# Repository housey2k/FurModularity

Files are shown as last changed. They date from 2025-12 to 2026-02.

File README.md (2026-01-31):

# FurModularity
Smart watch/audio mixer/module hub/game console/whatever
The FurModularity is a """watch""" meant "For Modularity", it's based on a ESP32-S3 as it's brain

It has 5 input/output connectors for external modules, these modules can be anything, be it a flashlight, a laser pointer, SD card, a second screen, or anything you can imagine, these modules interface with the main board through a SPI bus, a microcontroller inside the module card must interface between the actual module device and the ESP32, this allows more flexibility since a driver on the watch and custom code on the slave microcontroller allows for way more customization than directly interfacing the SPI bus with the module device, it would result in a way more limited module selection, or require you to manually select what kind of module is connected on the user inteface, which would ruin the hotplugging since you'd need to open settings every time you connect something new.

It also has a two input and two output audio mixer, via software you can route inputs 1, 2 or both to outputs 1, 2 or both, the routing is done by two 74VHC4066M Analog Switch ICs, one for each input channel, and you can also change the input volumes, that is done by two MCP4261 ICs, one for each channel too.

I originally built this project as a curious kid exploring CAD software, and I always liked electronics, I wanted to create my own stuff, but I never had the money for it. Now with more experience I restarted this project from scratch hoping to get funds for it.

This is how the PCB looks like, the back side has no components, thus simplifying assembly:

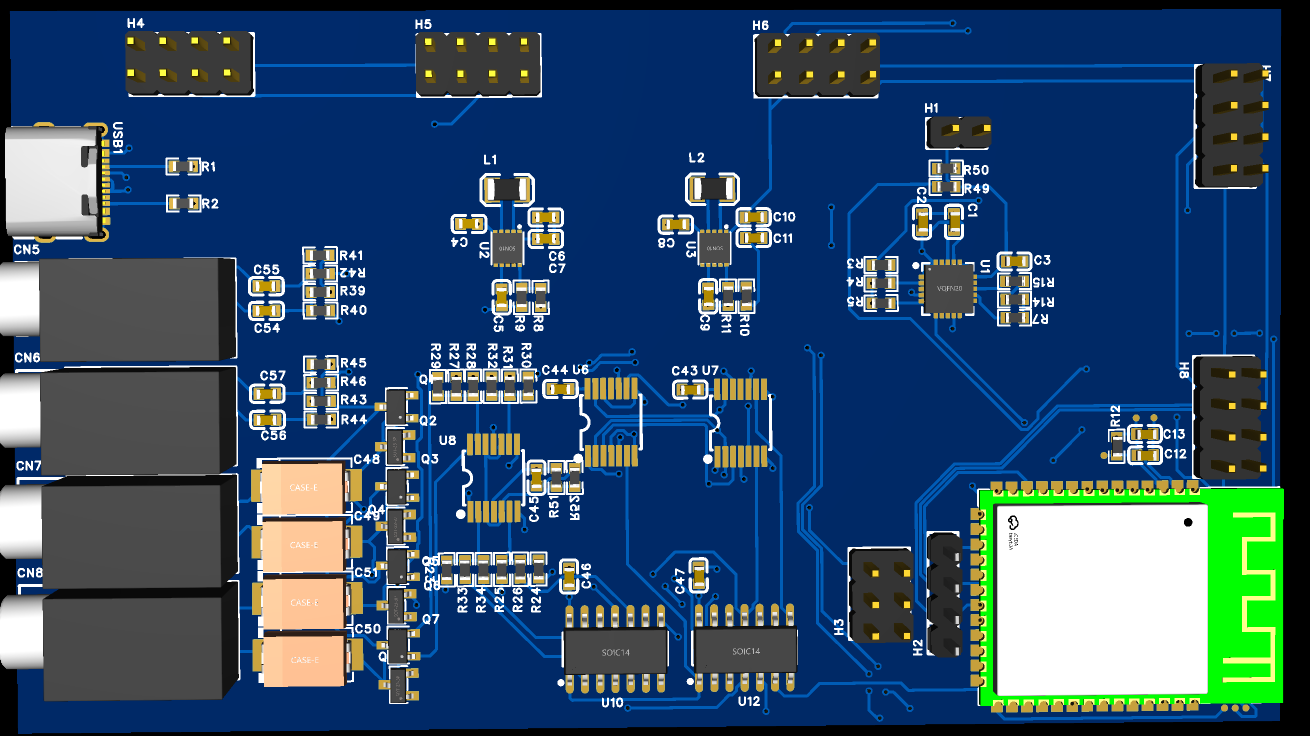
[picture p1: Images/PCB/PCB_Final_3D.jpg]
Board image

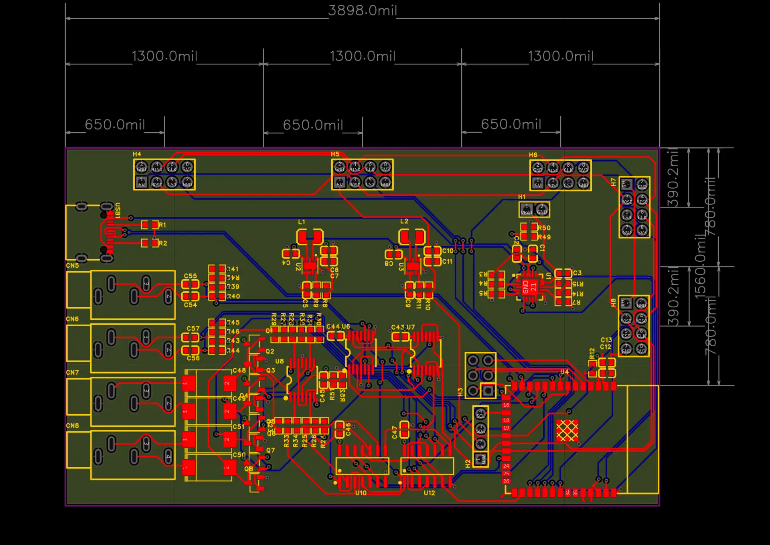
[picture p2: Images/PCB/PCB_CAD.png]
Board routing


This is how the case looks like:

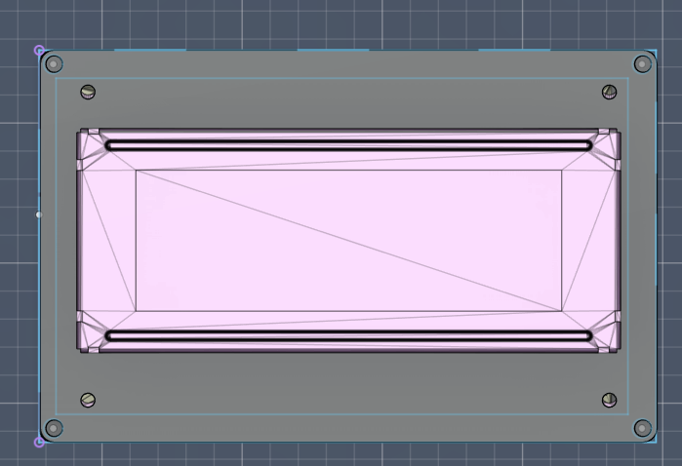
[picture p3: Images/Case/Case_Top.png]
Case

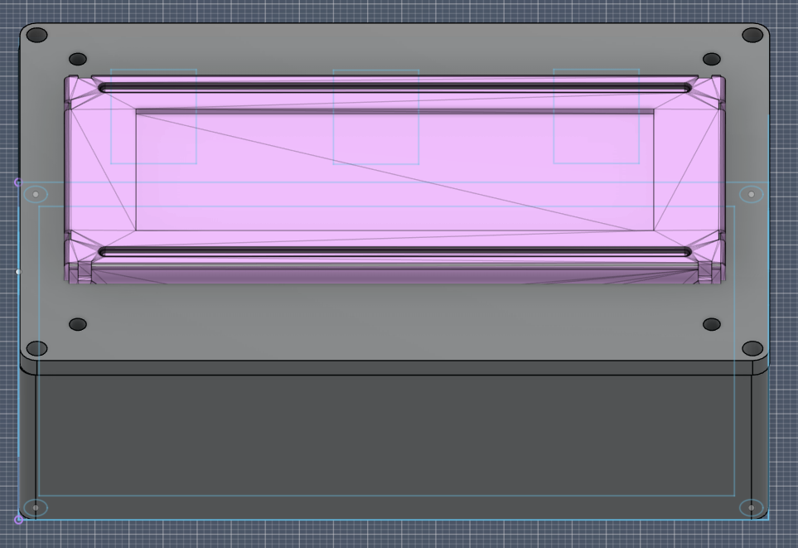
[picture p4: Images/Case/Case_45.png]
Case2

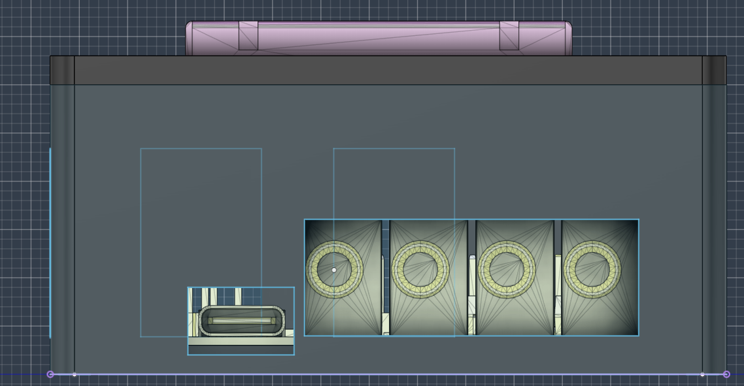
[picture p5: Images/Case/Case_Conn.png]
Case3

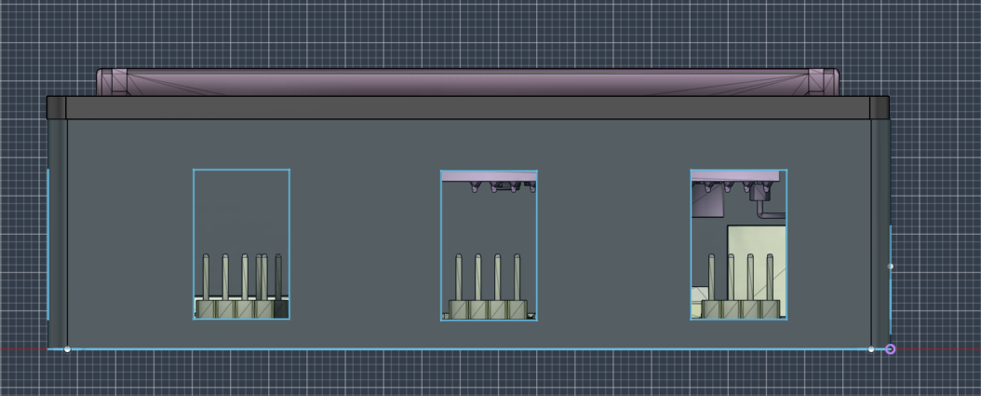
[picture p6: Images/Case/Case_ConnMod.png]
Case4


And finally, here is the schematics:
This is the power circuit, it handles battery discharging, PowerPath, and generating 5V and 3.3V rails

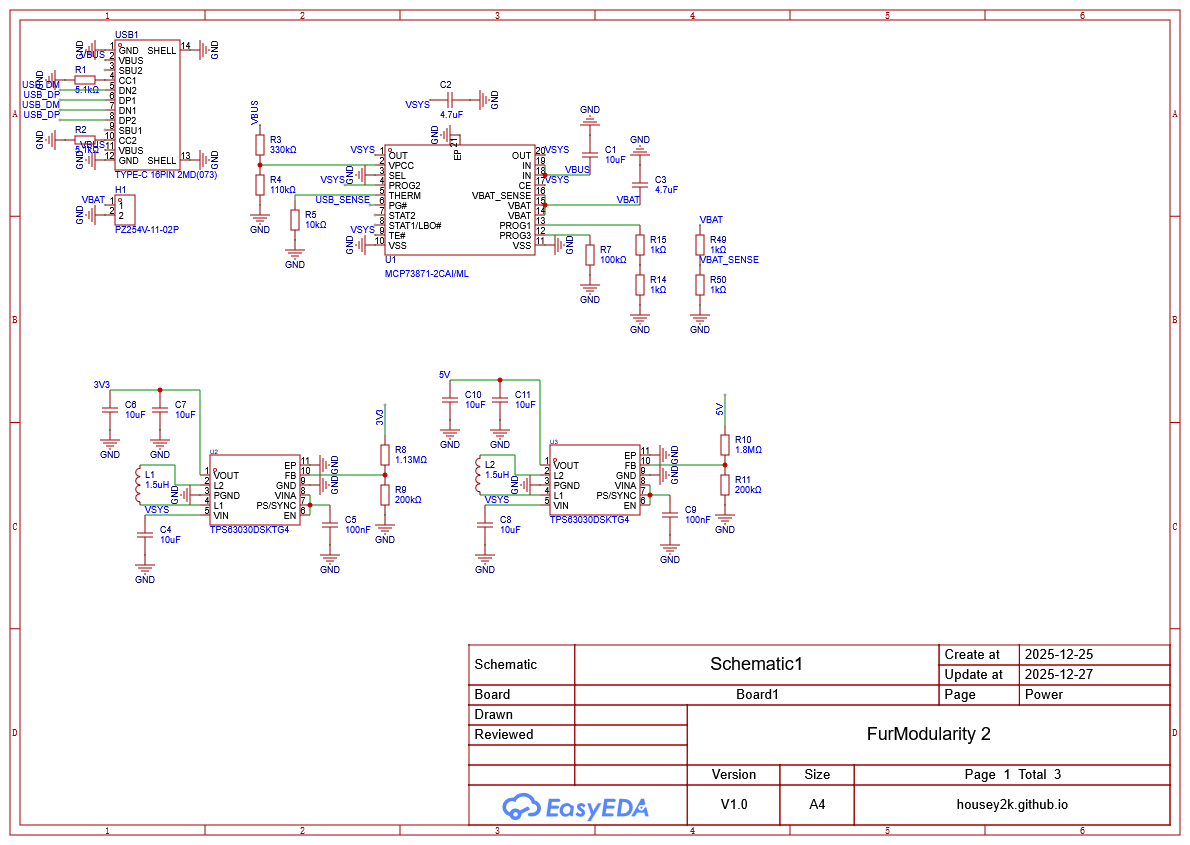
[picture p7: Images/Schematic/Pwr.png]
Power circuit


This is the digital circuit, it shows connections from the MCU to other components in the board

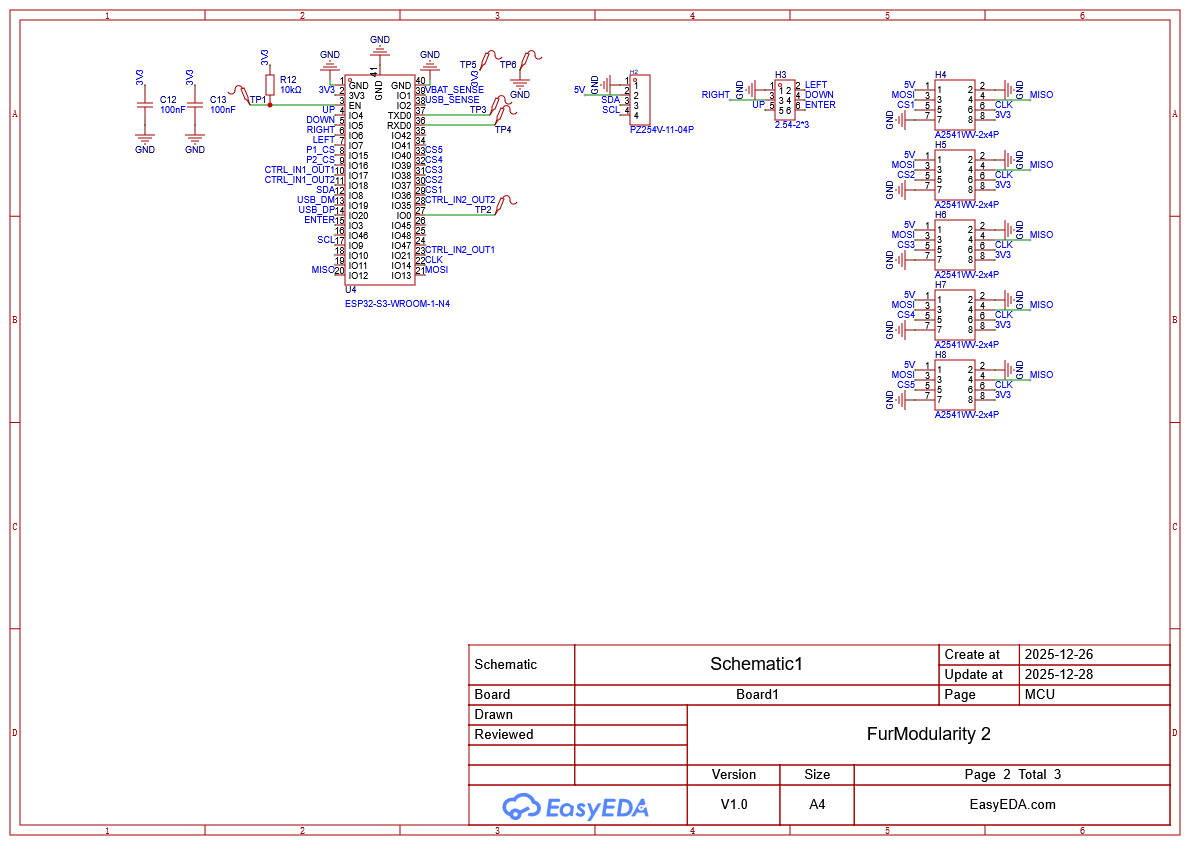
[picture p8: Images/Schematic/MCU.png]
Digital circuit


This is the audio circuit, it handles audio routing and volume control, everything is controlled by the MCU

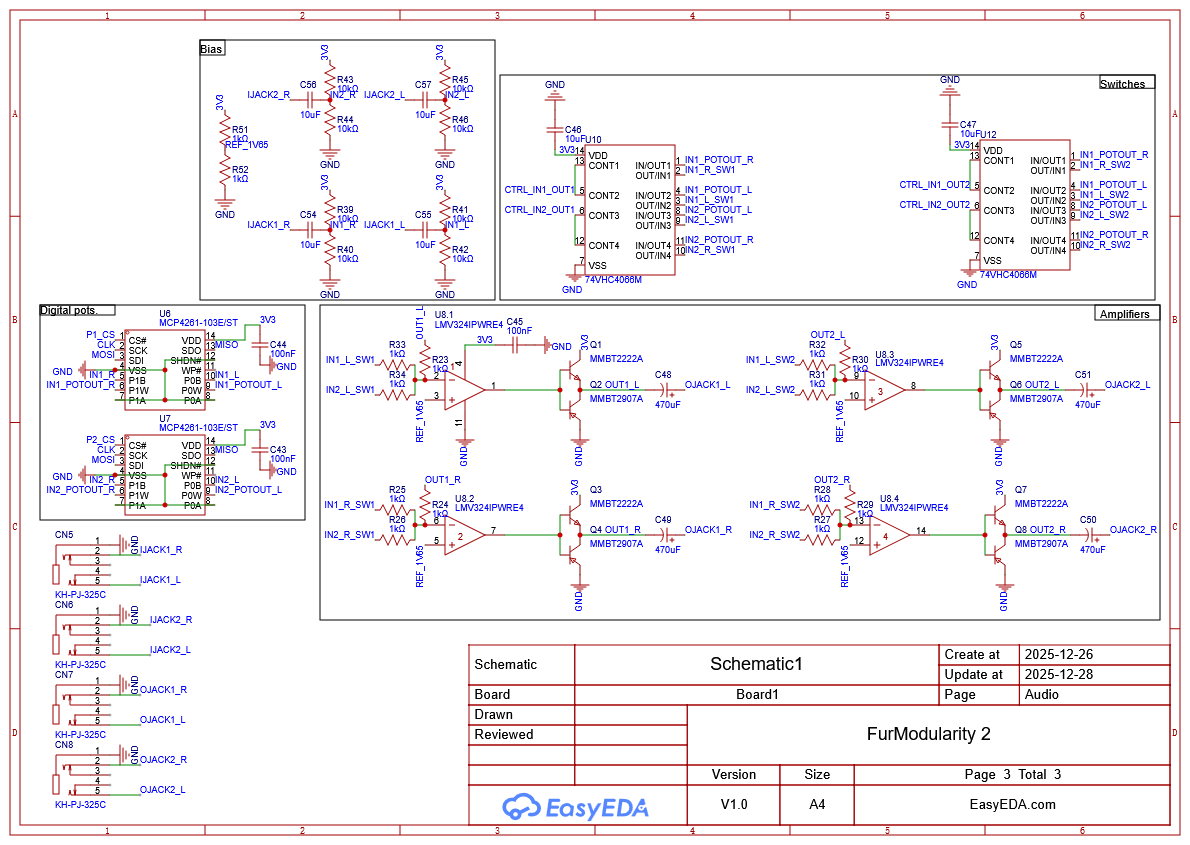
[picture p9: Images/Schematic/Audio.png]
Audio circuit


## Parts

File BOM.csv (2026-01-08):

No. | Quantity | Comment | Designator | Footprint | Value | Manufacturer Part | Manufacturer | Supplier Part | Supplier | LCSC Price | LCSC Stock | JLCPCB Price | Pin Count | Primary Category | Secondary Category | JLCPCB Stock
1 | 13 | 10uF | C1,C4,C6,C7,C8,C10,C11,C46,C47,C54,C55,C56,C57 | C0603 | 10uF | C0603B106M007T | IHHEC(禾伸堂) | C7094065 | LCSC |  |  | 0.0012 | 2 |  |  | 3671
2 | 2 | 4.7uF | C2,C3 | C0603 | 4.7uF | CL10A475KP8NNNC | SAMSUNG(三星) | C1705 | LCSC |  |  | 0.0008 | 2 |  |  | 3474753
3 | 7 | 100nF | C5,C9,C12,C13,C43,C44,C45 | C0603 | 100nF | CC0603KRX7R9BB104 | YAGEO(国巨) | C14663 | LCSC |  |  | 0.0004 | 2 |  |  | 44214790
4 | 4 | 470uF | C48,C49,C50,C51 | CAP-SMD_L7.3-W4.3-FD | 470uF | CA45-D-6.3V-470UF-K | CEC(振华新云) | C2841148 | LCSC |  |  | 0.1091 | 2 |  |  | 371
5 | 4 | KH-PJ-325C | CN5,CN6,CN7,CN8 | AUDIO-TH_KH-PJ-325C |  | KH-PJ-325C | kinghelm(金航标) | C5123138 | LCSC |  |  | 0.0272 | 5 | Connectors | Audio Connectors | 425
6 | 1 | PZ254V-11-02P | H1 | HDR-TH_2P-P2.54-V-M |  | PZ254V-11-02P | XFCN(兴飞) | C492401 | LCSC |  |  | 0.0018 | 2 | Connectors | Pin Headers | 466269
7 | 1 | PZ254V-11-04P | H2 | HDR-TH_4P-P2.54-V-M |  | PZ254V-11-04P | XFCN(兴飞) | C2691448 | LCSC |  |  | 0.0032 | 4 | Connectors | Pin Headers | 536292
8 | 1 | 2.54-2*3 | H3 | HDR-TH_6P-P2.54-V-R2-C3-S2.54_A2541WV-2X3P |  | 2.54-2*3 | ZHOURI(洲日) | C5116479 | LCSC |  |  | 0.0084 | 6 |  |  | 16100
9 | 5 | A2541WV-2x4P | H4,H5,H6,H7,H8 | HDR-TH_8P-P2.54-V-R2-C4-S2.54_A2541WV-2X4P |  | A2541WV-2x4P | CJT(长江连接器) | C225519 | LCSC |  |  | 0.0185 | 8 | Connectors | Pin Headers | 8767
10 | 2 | 1.5uH | L1,L2 | L1207 | 1.5uH | LB3218T1R5M | TAIYO YUDEN(太诱) | C223380 | LCSC |  |  | 0.0067 | 2 |  |  | 0
11 | 4 | MMBT2222A | Q1,Q3,Q5,Q7 | SOT-23-3_L2.9-W1.6-P1.90-LS2.8-BR |  | MMBT2222A | TDSEMIC(拓电半导体) | C42441802 | LCSC |  |  |  | 3 | Transistors/Thyristors | Bipolar (BJT) | 0
12 | 4 | MMBT2907A | Q2,Q4,Q6,Q8 | SOT-23-3_L2.9-W1.3-P1.90-LS2.4-BR |  | MMBT2907A | R+O(宏嘉诚) | C7420352 | LCSC |  |  | 0.002 | 3 | Transistors/Thyristors | Bipolar (BJT) | 61513
13 | 2 | 5.1kΩ | R1,R2 | R0603 | 5.1kΩ | HoAR0603-1/10W-5.1KR-0.1%-TCR25 | Milliohm(毫欧) | C5123587 | LCSC |  |  | 0.0074 | 2 |  |  | 886
14 | 1 | 330kΩ | R3 | R0603 | 330kΩ | HPCR0603F330KK9 | RESI(开步睿思) | C365145 | LCSC |  |  | 0.0001 | 2 |  |  | 0
15 | 1 | 110kΩ | R4 | R0603 | 110kΩ | PTFR0603B110KN9 | RESI(开步睿思) | C2692888 | LCSC |  |  | 0.0264 | 2 |  |  | 3493
16 | 10 | 10kΩ | R5,R12,R39,R40,R41,R42,R43,R44,R45,R46 | R0603 | 10kΩ | SCR0603J10K | VO(翔胜) | C3017715 | LCSC |  |  | 0.0002 | 2 |  |  | 101148
17 | 1 | 100kΩ | R7 | R0603 | 100kΩ | SCR0603F100K | VO(翔胜) | C3016388 | LCSC |  |  | 0.0002 | 2 |  |  | 11345
18 | 1 | 1.13MΩ | R8 | R0603 | 1.13MΩ | RTT031134FTP | RALEC(旺诠) | C166907 | LCSC |  |  | 0.0003 | 2 |  |  | 2926
19 | 2 | 200kΩ | R9,R11 | R0603 | 200kΩ | SCR0603F200K | VO(翔胜) | C5140262 | LCSC |  |  | 0.0002 | 2 |  |  | 14229
20 | 1 | 1.8MΩ | R10 | R0603 | 1.8MΩ | FRC0603J185TS | FOJAN(富捷) | C2930026 | LCSC |  |  | 0.0002 | 2 |  |  | 52798
21 | 18 | 1kΩ | R14,R15,R23,R24,R25,R26,R27,R28,R29,R30,R31,R32,R33,R34,R49,R50,R51,R52 | R0603 | 1kΩ | 0603WAF1001T5E | UNI-ROYAL(厚声) | C21190 | LCSC |  |  | 0.0002 | 2 |  |  | 38137816
22 | 6 | Test-Point | TP1,TP2,TP3,TP4,TP5,TP6 | Test-Point-0.5mm |  |  |  |  |  | 47.3558 |  |  | 1
23 | 1 | MCP73871-2CAI/ML | U1 | QFN-20_L4.0-W4.0-P0.50-BL-EP2.7 |  | MCP73871-2CAI/ML | MICROCHIP(美国微芯) | C185603 | LCSC |  |  | 0.5949 | 21 | Power Management (PMIC) | Battery Management | 89
24 | 2 | TPS63030DSKTG4 | U2,U3 | SON-10_L2.5-W2.5-P0.50-TL-EP |  | TPS63030DSKTG4 | TI(德州仪器) | C2072808 | LCSC |  |  | 0.2499 | 11 | Power Management (PMIC) | DC-DC Converters | 0
25 | 1 | ESP32-S3-WROOM-1-N4 | U4 | WIFIM-SMD_ESP32-S3-WROOM-1-N8 |  | ESP32-S3-WROOM-1-N4 | ESPRESSIF(乐鑫) | C2913197 | LCSC |  |  | 0.6377 | 41 | IoT/Communication Modules | WiFi Modules | 82
26 | 2 | MCP4261-103E/ST | U6,U7 | TSSOP-14_L5.0-W4.4-P0.65-LS6.4-BL |  | MCP4261-103E/ST | MICROCHIP(美国微芯) | C185580 | LCSC |  |  | 0.2985 | 14 |  |  | 0
27 | 1 | LMV324IPWRE4 | U8 | TSSOP-14_L5.0-W4.4-P0.65-LS6.4-BL |  | LMV324IPWRE4 | TI(德州仪器) | C4366614 | LCSC |  |  | 0.044 | 14 |  |  | 0
28 | 2 | 74VHC4066M | U10,U12 | SOIC-14_L8.7-W3.9-P1.27-LS6.0-BL |  | 74VHC4066M | onsemi(安森美) | C3656918 | LCSC |  |  | 0.0376 | 14 |  |  | 0
29 | 1 | TYPE-C 16PIN 2MD(073) | USB1 | USB-C-SMD_TYPE-C-6PIN-2MD-073 |  | TYPE-C 16PIN 2MD(073) | SHOU HAN(首韩) | C2765186 | LCSC |  |  | 0.0092 | 14 | Connectors | USB Connectors | 874554

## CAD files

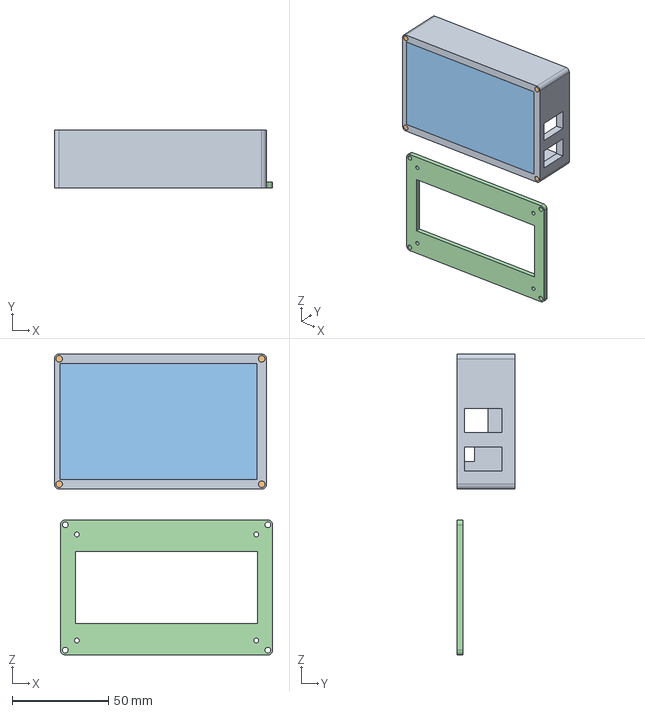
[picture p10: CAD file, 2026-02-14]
3D files/FurModularity case.step
113.2 x 30.0 x 156.0 mm

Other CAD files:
3D files/FurModularity case.f3d

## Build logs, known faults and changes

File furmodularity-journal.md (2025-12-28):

<!--
  This journal is auto generated by Hack Club Blueprint.
-->

## 12/26/2025 4 PM - Designed power circuit  

_Time spent: 2.0h_  

The foundation of every circuit is it's power, so my first step to designing a board is designing the power circuit
I started adding connectors for USB-C charging, and LiPo battery
I added a MCP73871 (Load Sharing and Battery Charge Controller) to handle USB and LiPo power, and two TPS63030, these ICs generate the 3.3V and 5V rails that will be used to power the microcontroller and peripherals with 3.3V, and 5V to power the LCD backlight and audio circuit!
Power circuit

## 12/26/2025 6 PM - Partial MCU  

_Time spent: 1.4h_  

I picked a ESP32-S3 for this project due to its high processing power and easy to implement board with built in antenna and decoupling circuits.
I already added button input and LCD output, I'll be adding audio control lines once the audio circuit is finshed
MCU

## 12/26/2025 9 PM - Finished designing audio circuit  

_Time spent: 2.7h_  

I finished designing the audio circuit
For volume, I picked the MCP4261 because it's a popular digital potentiometer IC that's well documented and has libraries for it.
I used the 74VHC4066N Quad Analog Switch for routing inputs to outputs, it's a modern and simple IC.
I'm using the LMV324 because it's similiar to the popular LM324, but suitable for low voltage rail-to-rail operation.
Now we have a basic mixer inside the device, with two inputs and two outputs, you can route inputs A, B or both to outputs A, B, or both, and you can also tweak inputs A and B volume
This is how the audio circuit turned out:
Audio circuit
This is how the MCU turned circuit turned out:
MCU

## 12/26/2025 10 PM - Added module headers, finished MCU design  

_Time spent: 0.3h_  

Added connectors for the modules, the original design was supposed to have 4 modules, but I switched to 5 because there was A LOT of free GPIO
Header schematics
This is how the finished MCU looks like
MCU

## 12/27/2025 12 AM - Finished PCB layout + schematic changes  

_Time spent: 1.5h_  

I just finished the PCB layout, this is how it looks so far:
PCB
A few changes were made to the circuit:
Power
On the power circuit, I added a VBAT sense voltage divider so the microcontroller can know the battery voltage level, and a charge sense through the MCP's PG# pin
This is how the MCU looks like with the added lines:
MCU

## 12/27/2025 12 PM - Changed reference voltage for summing amplifiers  

_Time spent: 0.5h_  

Today I learned that when working with a single rail summing amplifier circuit, we cannot put GND on the non inverting input like we see on many schematics on the internet. We should actually reference it to 1/2VCC (That's 0V if it was a dual rail circuit). So I did a small change of putting a voltage divider on the 3.3V line and replacing GND with a line called `REF_1V65` on all the op-amps, below you can see the voltage divider I created:
Divider
And here is how it looks on the amplifiers:
amps

## 12/27/2025 2 PM - Changed PCB layout due to RF concerns  

_Time spent: 2.8h_  

On the previous board the ESP32 was around the middle of the board, but I learned that the antenna should be positioned in the board edge for better signal quality, less noise in the circuit and less power used.
Since there was a lot of free space I also changed the position of the buck/boost converters and made them more spaced for thermal and noise concerns. This involved rerouting parts of these sectors
This is how the board looks now midway through routing:
Board

## 12/27/2025 3 PM - Connected buttons to GPIO  

_Time spent: 0.2h_  

There's not much to talk here, it's just that I forgot to connect the button lines to the ESP32.
I realized it while I was routing the board and saw that there are no ratlines. It was a pretty quick fix


## 12/27/2025 6 PM - Finished PCB  

_Time spent: 3.0h_  

After A LOT of suffering and layout changes, I received some feedback and I decided to switch to a 4 layer PCB with a ground and a 3.3V plane, that made the board way cleaner since now there are solid power and ground planes that are way less likely to have noise or voltage drop issues.
I also switched the inductors L1 and L2 to a L1207 packaging, that made them way smaller, this is how the actual final PCB looks like:
PCB

## 12/27/2025 7 PM - USB pins change  

_Time spent: 0.3h_  

I just learned that the USB pins are one of the few things that are NOT handled by the ESP32's internal IOMUX, they are fixed to GPIOs 19 and 20, so I had to switch D- to GPIO19, D+ to GPIO20, and CTRL_IN2_OUT1 to IO21, This is how the MCU side looks now:

And this is how the MCU looks on the PCB:


## 12/27/2025 11 PM - Started writing firmware  

_Time spent: 3.0h_  

Started writing the WIP firmware, I already have a hopefully working sketch that performs the power-on-self-test (it interacts with the digital potentiometer's to confirm they are connected and working, at least I think that is really fancy), and then writes the main menu, and allows you to move an arrow around that later when you click enter it will go into a sub-menu.
The complete firmware is avaiable at the GitHub repository


## 12/28/2025 12 PM - Started rerouting PCB... Again😵‍💫  

_Time spent: 1.0h_  

I did my PCB without noticing that it was slightly wider than 100mm, that generates a big engineering fee. I tried partially rerouting by copying and pasting the old traces, the only part I touched was the MCU and module connectors, but stuff kept breaking on the whole board so I'm just doing it again


## 12/28/2025 2 PM - Finished PCB  

_Time spent: 2.8h_  

After a lot of work the board is finally ready, this time with no fees, now instead it costs $7.00, the earlier board had a $30+ engineering fee because of a few milimiters too big. This is how the board turned out:




## 12/28/2025 4 PM - Updated GitHub  

_Time spent: 1.0h_  

I just published the updated BOM, gerbers and schematics to the GitHub repository, I also received a lot of cool feedback from a different engineering community, while that made me change the PCB a bunch of times, hopefully it will work flawlessly after assembly


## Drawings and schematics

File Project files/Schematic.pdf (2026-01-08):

# VBUS GND GND GND

# GNDVBUS

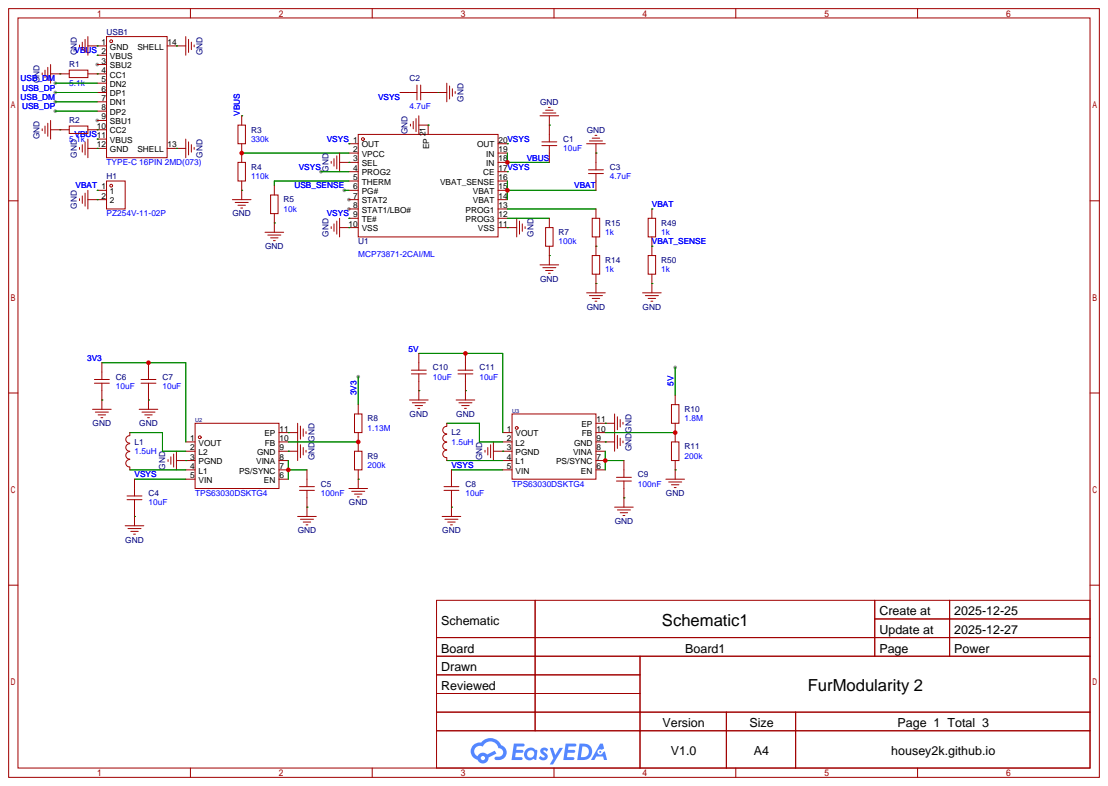
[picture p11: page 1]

Schematic | Schematic1 | Create at | 2025-12-25

Update at | 2025-12-27

Board | Board1 | Page | Power
Drawn | | FurModularity 2
Reviewed

Version | Size | Page 1 Total 3
V1.0 | A4 | housey2k.github.io

IO12 20 IO13 21 IO14 22 IO21 23 IO47 24 IO48 25 IO45 26 IO0 27 IO35 28 IO36 29 IO37 30 IO38 31 IO39 32 IO40 33 IO41 34 IO42 35 RXD0 36 TXD0 37 IO2 38 IO1 39 GND 40 GND ⁴¹

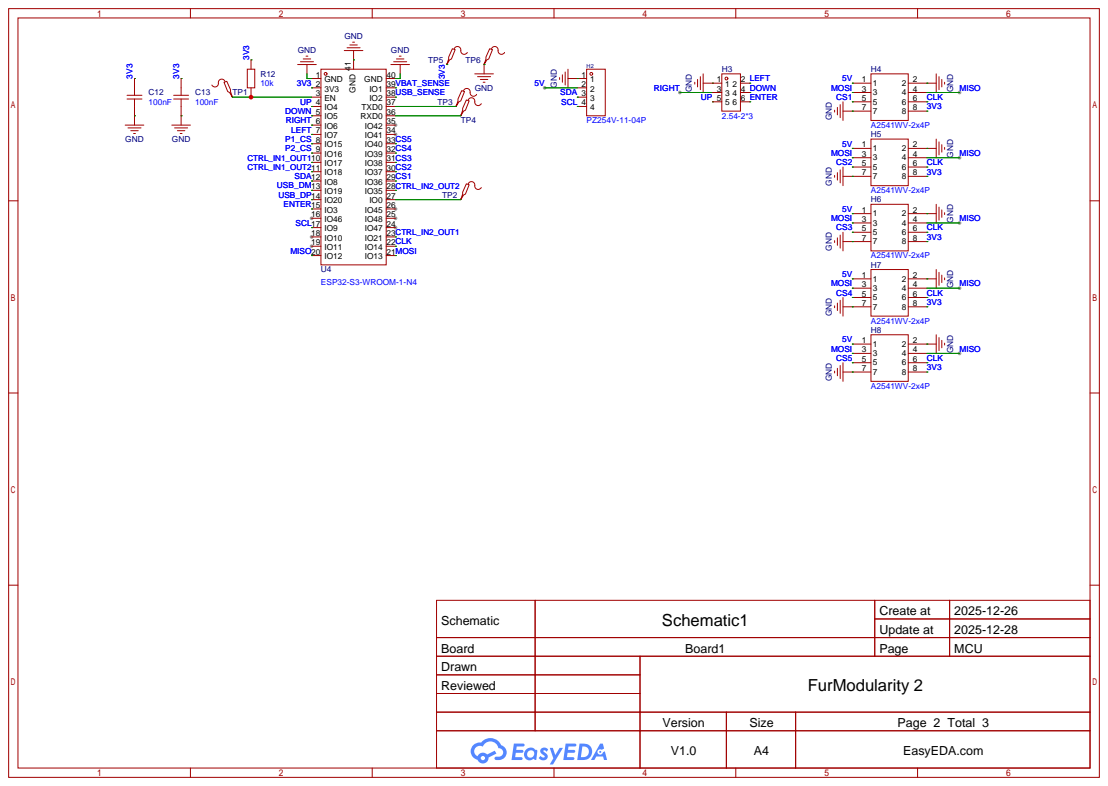
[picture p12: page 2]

Schematic | Schematic1 | Create at | 2025-12-26

Update at | 2025-12-28

Board | Board1 | Page | MCU
Drawn | | FurModularity 2
Reviewed

Version | Size | Page 2 Total 3
V1.0 | A4 | EasyEDA.com

# GND³V³

# GND³V³

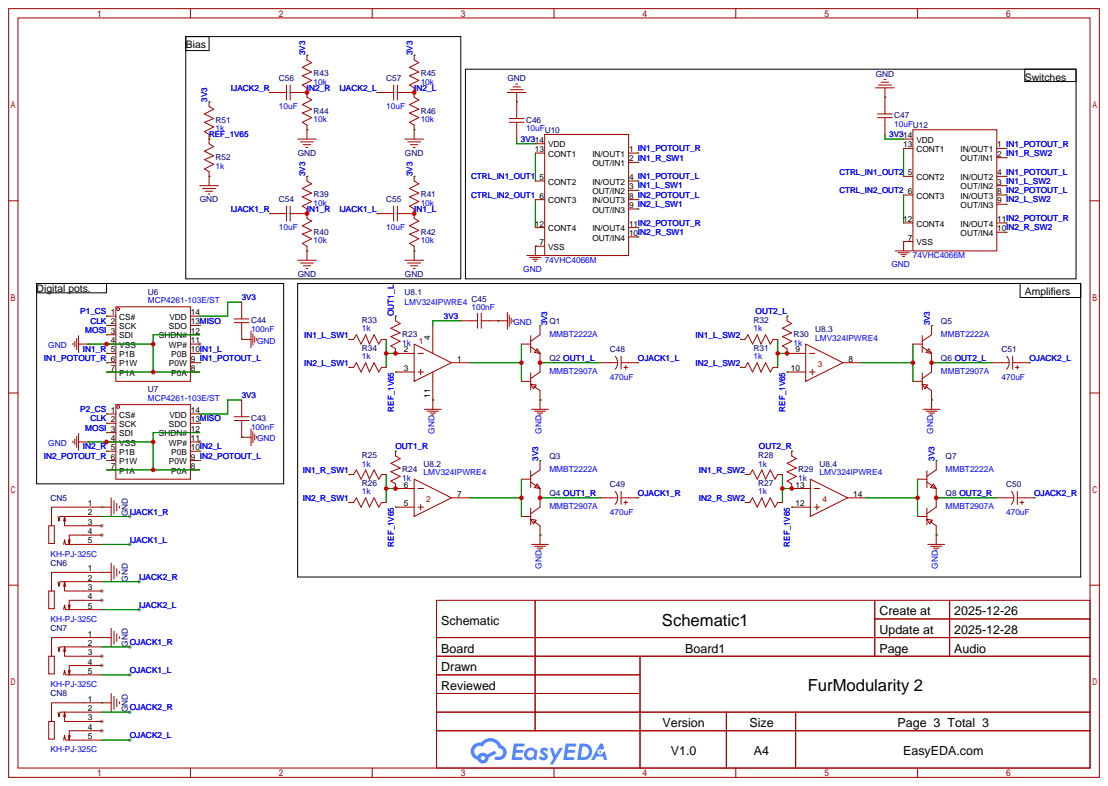
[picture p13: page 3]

GND GND
IJACK1_R

Schematic | Schematic1 | Create at | 2025-12-26

Update at | 2025-12-28

Board | Board1 | Page | Audio
Drawn | | FurModularity 2
Reviewed

Version | Size | Page 3 Total 3
V1.0 | A4 | EasyEDA.com

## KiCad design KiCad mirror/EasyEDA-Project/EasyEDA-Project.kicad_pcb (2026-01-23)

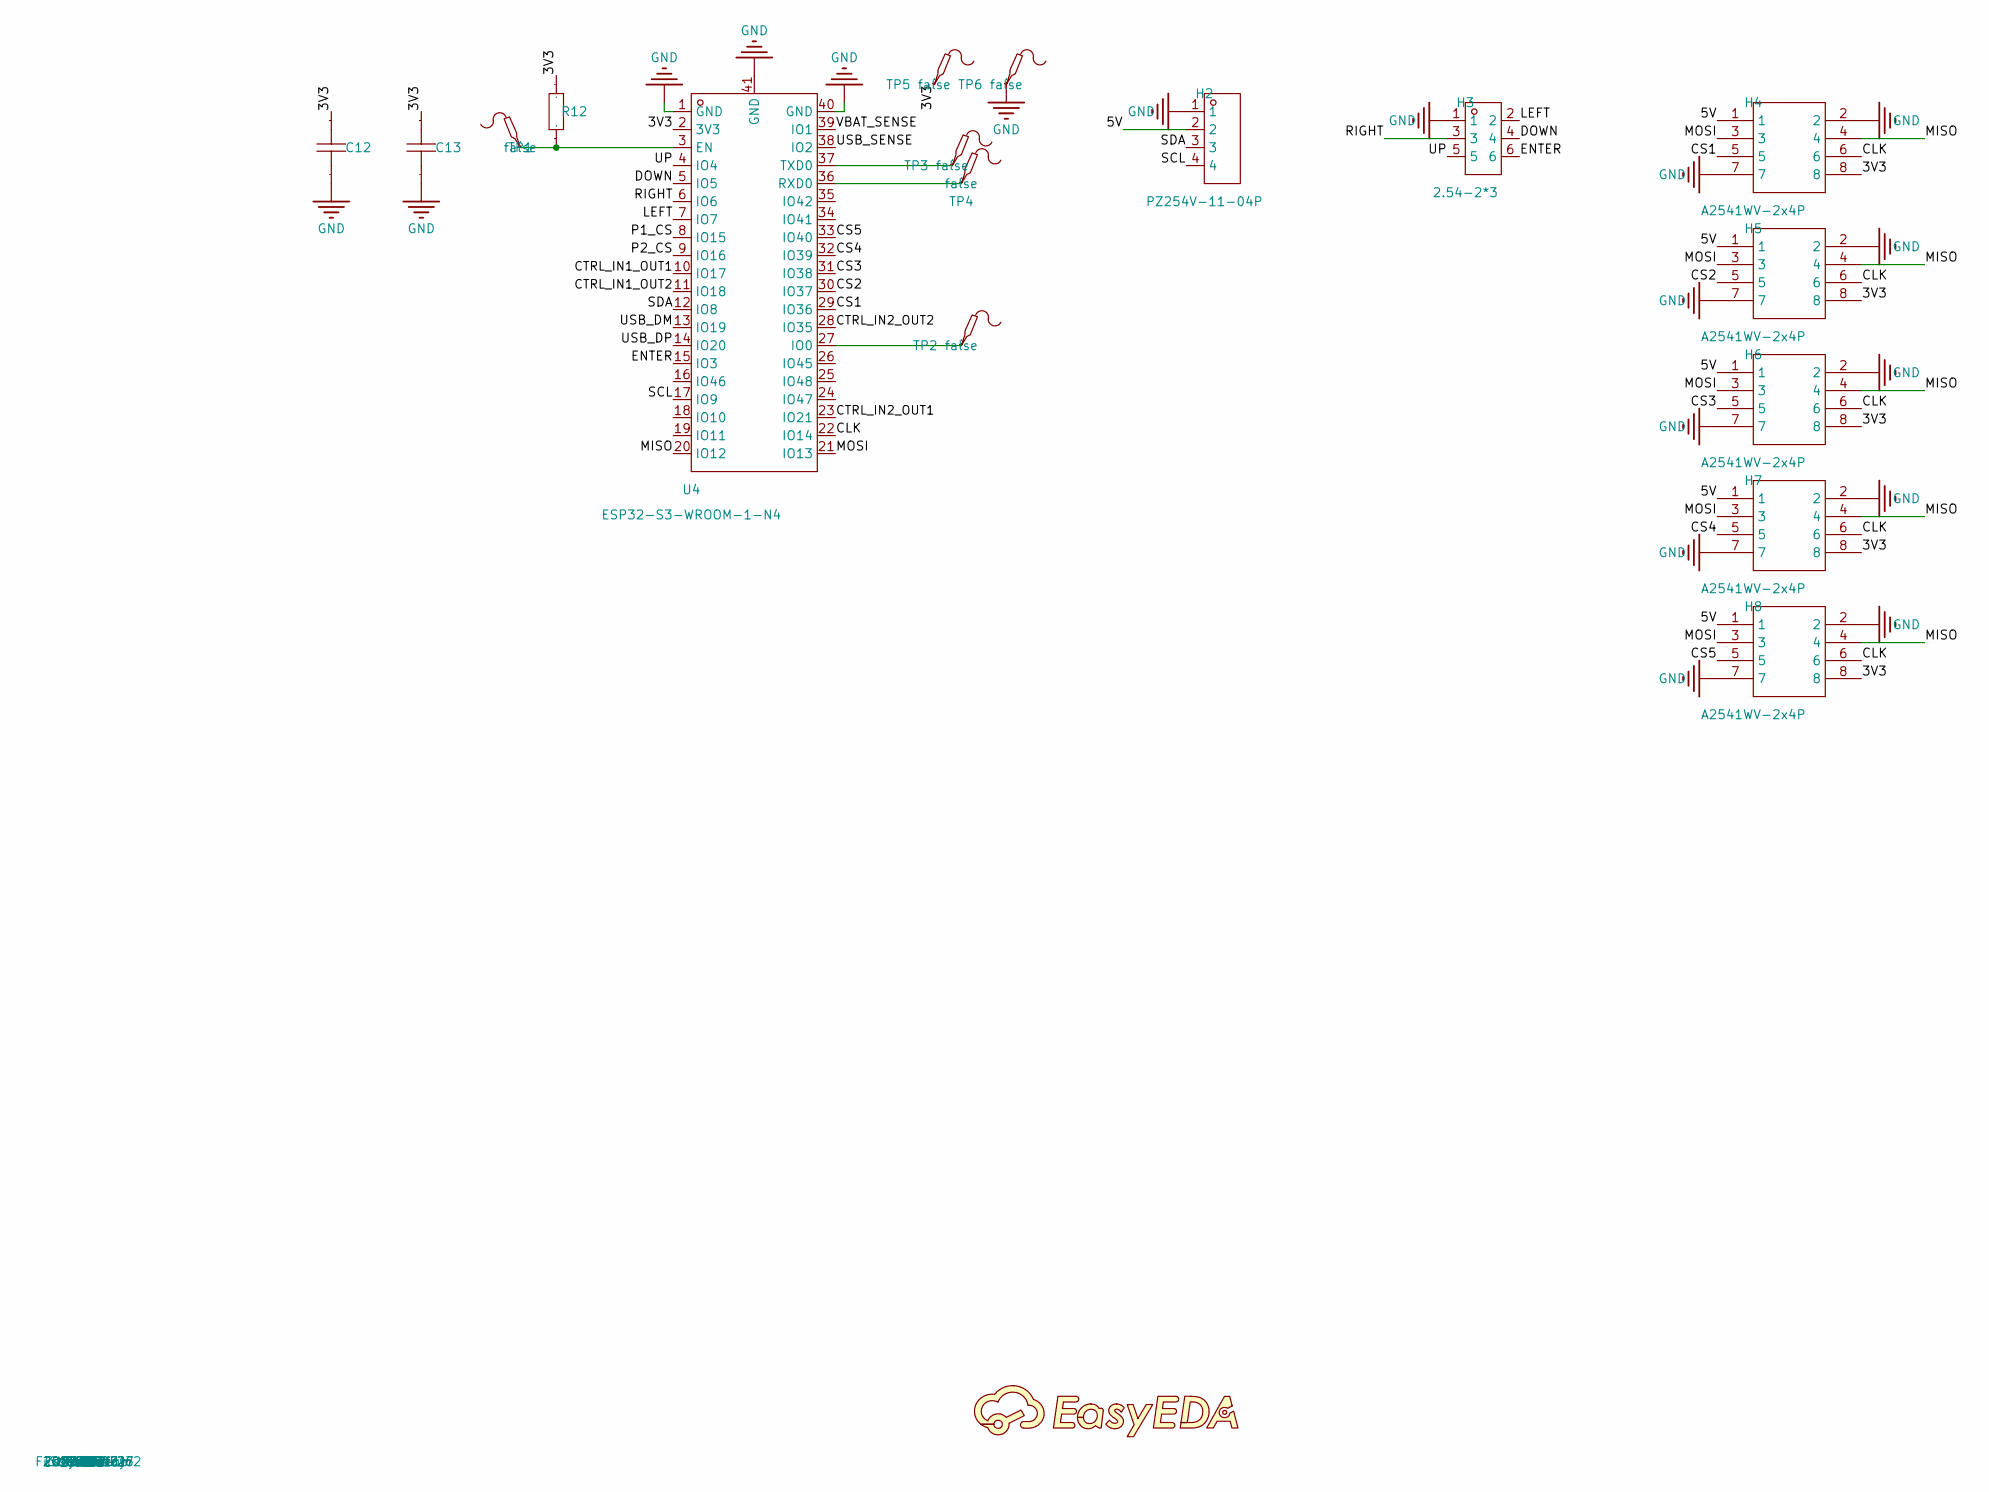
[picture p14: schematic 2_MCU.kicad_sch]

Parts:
C12, C13: 100nF; C0603; Manufacturer Part CC0603KRX7R9BB104; LCSC Part Name 100nF ±10% 50V
H2: PZ254V-11-04P; HDR-TH_4P-P2.54-V-M; Manufacturer Part PZ254V-11-04P; LCSC Part Name 1x4P 间距:2.54mm 方针 直插
H3: 2.54-2*3; HDR-TH_6P-P2.54-V-R2-C3-S2.54_A2541WV-2X3P; Manufacturer Part 2.54-2*3; LCSC Part Name 2x3P 间距:2.54mm 方针 直插
H4, H5, H6, H7, H8: A2541WV-2x4P; HDR-TH_8P-P2.54-V-R2-C4-S2.54_A2541WV-2X4P; Manufacturer Part A2541WV-2x4P; LCSC Part Name 2x4P 间距:2.54mm 方针 直插
R12: 10kΩ; R0603; Manufacturer Part SCR0603J10K; LCSC Part Name 厚膜电阻 10kΩ ±5% 100mW
TP1, TP2, TP3, TP4, TP5, TP6: Test-Point-0.5mm
U4: ESP32-S3-WROOM-1-N4; WIFIM-SMD_ESP32-S3-WROOM-1-N8; Manufacturer Part ESP32-S3-WROOM-1-N4; LCSC Part Name 通用型Wi-Fi+低功耗蓝牙MCU模组

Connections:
3V3: C12.1, C13.1, H4.8, H5.8, H6.8, H7.8, H8.8, R12.2, TP5.1, U4.2 (3V3); also elsewhere on the board
5V: H2.2, H4.1, H5.1, H6.1, H7.1, H8.1; also elsewhere on the board
$2N491: TP2.1, U4.27 (IO0)
$2N495: R12.1, TP1.1, U4.3 (EN)
$2N518: TP3.1, U4.37 (TXD0)
$2N539: TP4.1, U4.36 (RXD0)
CLK: H4.6, H5.6, H6.6, H7.6, H8.6, U4.22 (IO14); also elsewhere on the board
CS1: H4.5, U4.29 (IO36)
CS2: H5.5, U4.30 (IO37)
CS3: H6.5, U4.31 (IO38)
CS4: H7.5, U4.32 (IO39)
CS5: H8.5, U4.33 (IO40)
CTRL_IN1_OUT1: U4.10 (IO17); also elsewhere on the board
CTRL_IN1_OUT2: U4.11 (IO18); also elsewhere on the board
CTRL_IN2_OUT1: U4.23 (IO21); also elsewhere on the board
CTRL_IN2_OUT2: U4.28 (IO35); also elsewhere on the board
DOWN: H3.4, U4.5 (IO5)
ENTER: H3.6, U4.15 (IO3)
LEFT: H3.2, U4.7 (IO7)
MISO: H4.4, H5.4, H6.4, H7.4, H8.4, U4.20 (IO12); also elsewhere on the board
MOSI: H4.3, H5.3, H6.3, H7.3, H8.3, U4.21 (IO13); also elsewhere on the board
P1_CS: U4.8 (IO15); also elsewhere on the board
P2_CS: U4.9 (IO16); also elsewhere on the board
RIGHT: H3.3, U4.6 (IO6)
SCL: H2.4, U4.17 (IO9)
SDA: H2.3, U4.12 (IO8)
UP: H3.5, U4.4 (IO4)
USB_DM: U4.13 (IO19); also elsewhere on the board
USB_DP: U4.14 (IO20); also elsewhere on the board
USB_SENSE: U4.38 (IO2); also elsewhere on the board
VBAT_SENSE: U4.39 (IO1); also elsewhere on the board

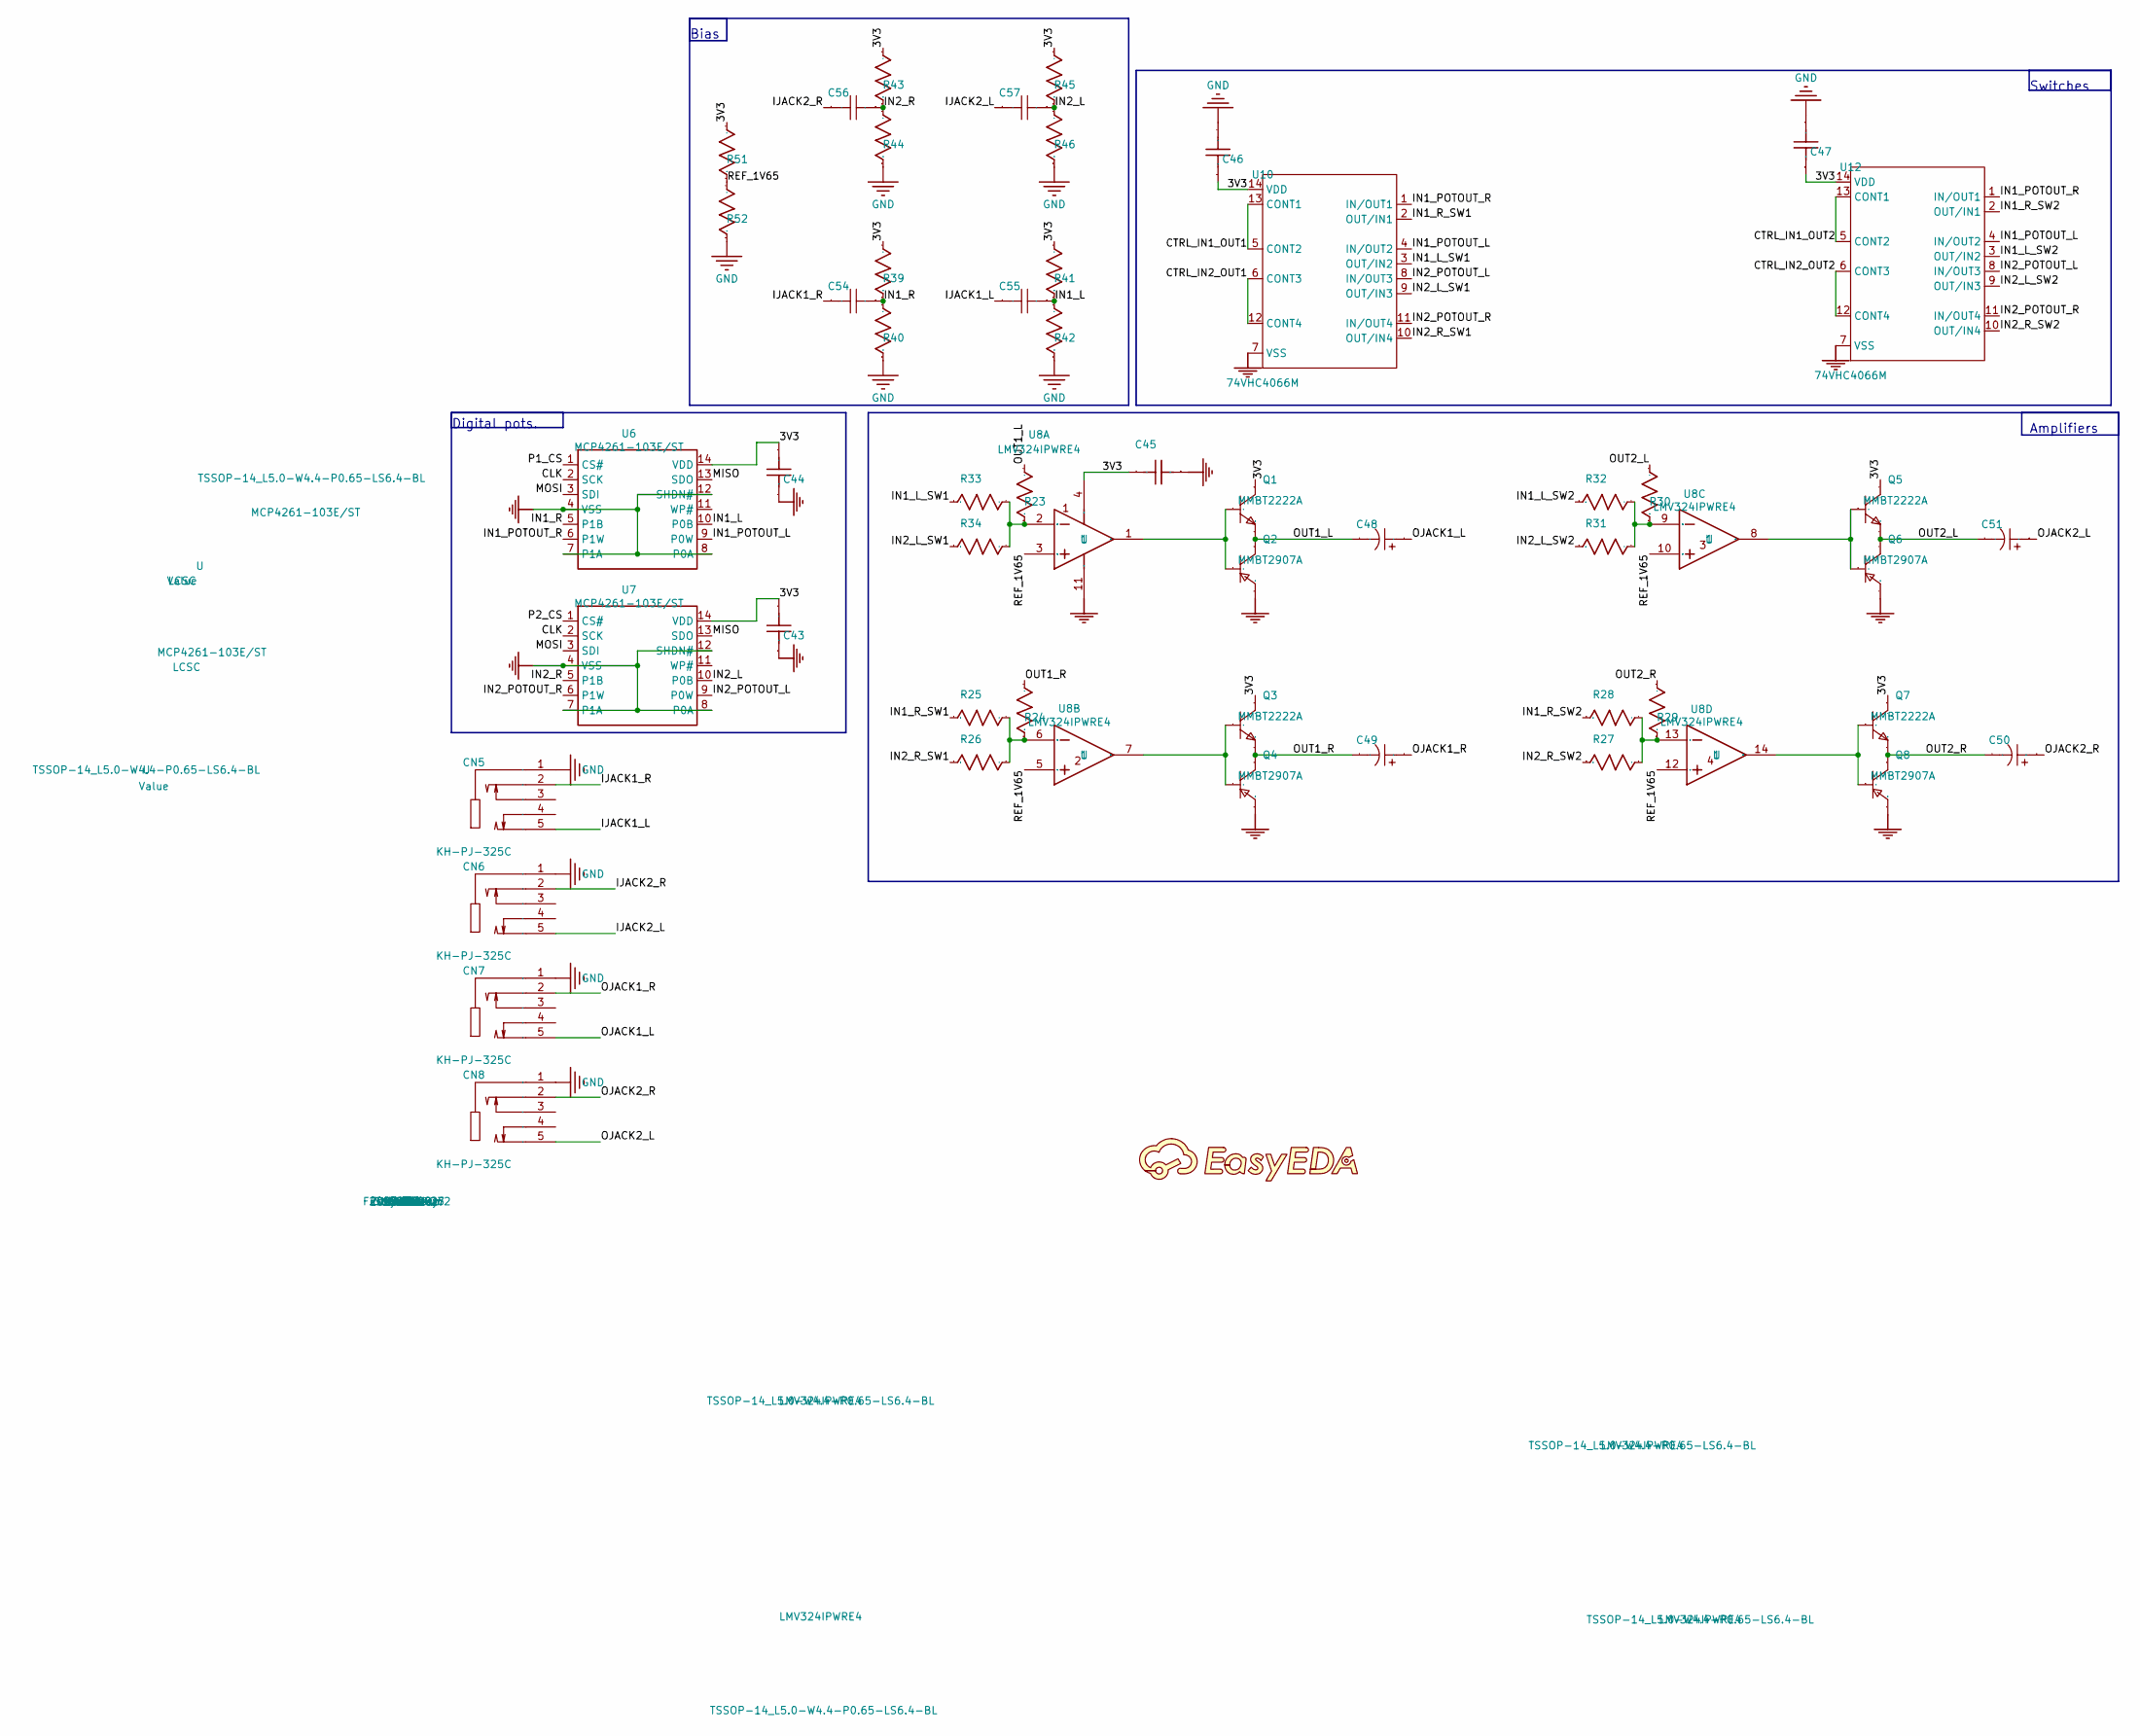
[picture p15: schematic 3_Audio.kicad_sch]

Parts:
C43, C44, C45: 100nF; C0603; Manufacturer Part CC0603KRX7R9BB104; LCSC Part Name 100nF ±10% 50V
C46, C47, C54, C55, C56, C57: 10uF; C0603; Manufacturer Part C0603B106M007T; LCSC Part Name 10uF ±20% 6.3V
C48, C49, C50, C51: 470uF; CAP-SMD_L7.3-W4.3-FD; Manufacturer Part CA45-D-6.3V-470UF-K; LCSC Part Name 470uF ±10% 6.3V
CN5, CN6, CN7, CN8: KH-PJ-325C; AUDIO-TH_KH-PJ-325C; Manufacturer Part KH-PJ-325C; LCSC Part Name 3.5mm耳机座
Q1, Q3, Q5, Q7: MMBT2222A; SOT-23-3_L2.9-W1.6-P1.90-LS2.8-BR; Manufacturer Part MMBT2222A; LCSC Part Name NPN 电流:0.6A 电压:40V
Q2, Q4, Q6, Q8: MMBT2907A; SOT-23-3_L2.9-W1.3-P1.90-LS2.4-BR; Manufacturer Part MMBT2907A; LCSC Part Name 电流:600mA 电压:60V
R23, R24, R25, R26, R27, R28, R29, R30, R31, R32, R33, R34, R51, R52: 1kΩ; R0603; Manufacturer Part 0603WAF1001T5E; LCSC Part Name 1kΩ ±1% 100mW 厚膜电阻
R39, R40, R41, R42, R43, R44, R45, R46: 10kΩ; R0603; Manufacturer Part SCR0603J10K; LCSC Part Name 厚膜电阻 10kΩ ±5% 100mW
U6, U7: MCP4261-103E/ST; TSSOP-14_L5.0-W4.4-P0.65-LS6.4-BL; Manufacturer Part MCP4261-103E/ST
U8: LMV324IPWRE4; TSSOP-14_L5.0-W4.4-P0.65-LS6.4-BL; Manufacturer Part LMV324IPWRE4
U10, U12: 74VHC4066M; PDIP-14_L19.7-W6.6-P2.54-LS8.3-BL; Manufacturer Part 74VHC4066M; LCSC Part Name 74VHC4066M

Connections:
3V3: C43.2, C44.2, C45.2, C46.1, C47.1, Q1.3 (C), Q3.3 (C), Q5.3 (C), Q7.3 (C), R39.2, R41.2, R43.2, R45.2, R51.2, U6.14 (VDD), U7.14 (VDD), U8.4 (VCC+), U10.14 (VDD), U12.14 (VDD); also elsewhere on the board
$3N1138: R23.1, R33.2, R34.2, U8.2 (1IN-)
$3N1139: R24.1, R25.2, R26.2, U8.6 (2IN-)
$3N1144: R27.2, R28.2, R29.1, U8.13 (4IN-)
$3N1145: R30.1, R31.2, R32.2, U8.9 (3IN-)
$3N1256: Q5.1 (B), Q6.1 (B), U8.8 (3OUT)
$3N2308: Q1.1 (B), Q2.1 (B), U8.1 (OUT)
$3N2351: Q3.1 (B), Q4.1 (B), U8.7 (2OUT)
$3N2603: Q7.1 (B), Q8.1 (B), U8.14 (4OUT)
CLK: U6.2 (SCK), U7.2 (SCK); also elsewhere on the board
CTRL_IN1_OUT1: U10.5 (CONT2), U10.13 (CONT1); also elsewhere on the board
CTRL_IN1_OUT2: U12.5 (CONT2), U12.13 (CONT1); also elsewhere on the board
CTRL_IN2_OUT1: U10.6 (CONT3), U10.12 (CONT4); also elsewhere on the board
CTRL_IN2_OUT2: U12.6 (CONT3), U12.12 (CONT4); also elsewhere on the board
IJACK1_L: C55.2, CN5.5
IJACK1_R: C54.2, CN5.2
IJACK2_L: C57.2, CN6.5
IJACK2_R: C56.2, CN6.2
IN1_L: C55.1, R41.1, R42.2, U6.10 (P0B)
IN1_L_SW1: R33.1, U10.3 (OUT/IN2)
IN1_L_SW2: R32.1, U12.3 (OUT/IN2)
IN1_POTOUT_L: U6.9 (P0W), U10.4 (IN/OUT2), U12.4 (IN/OUT2)
IN1_POTOUT_R: U6.6 (P1W), U10.1 (IN/OUT1), U12.1 (IN/OUT1)
IN1_R: C54.1, R39.1, R40.2, U6.5 (P1B)
IN1_R_SW1: R25.1, U10.2 (OUT/IN1)
IN1_R_SW2: R28.1, U12.2 (OUT/IN1)
IN2_L: C57.1, R45.1, R46.2, U7.10 (P0B)
IN2_L_SW1: R34.1, U10.9 (OUT/IN3)
IN2_L_SW2: R31.1, U12.9 (OUT/IN3)
IN2_POTOUT_L: U7.9 (P0W), U10.8 (IN/OUT3), U12.8 (IN/OUT3)
IN2_POTOUT_R: U7.6 (P1W), U10.11 (IN/OUT4), U12.11 (IN/OUT4)
IN2_R: C56.1, R43.1, R44.2, U7.5 (P1B)
IN2_R_SW1: R26.1, U10.10 (OUT/IN4)
IN2_R_SW2: R27.1, U12.10 (OUT/IN4)
MISO: U6.13 (SDO), U7.13 (SDO); also elsewhere on the board
MOSI: U6.3 (SDI), U7.3 (SDI); also elsewhere on the board
OJACK1_L: C48.1, CN7.5
OJACK1_R: C49.1, CN7.2
OJACK2_L: C51.1, CN8.5
OJACK2_R: C50.1, CN8.2
OUT1_L: C48.2, Q1.2 (E), Q2.3 (C), R23.2
OUT1_R: C49.2, Q3.2 (E), Q4.3 (C), R24.2
OUT2_L: C51.2, Q5.2 (E), Q6.3 (C), R30.2
OUT2_R: C50.2, Q7.2 (E), Q8.3 (C), R29.2
P1_CS: U6.1 (CS#); also elsewhere on the board
P2_CS: U7.1 (CS#); also elsewhere on the board
REF_1V65: R51.1, R52.2, U8.3 (1IN+), U8.5 (2IN+), U8.10 (3IN+), U8.12 (4IN+)

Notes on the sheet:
Amplifiers
Bias
Switches
Digital pots.

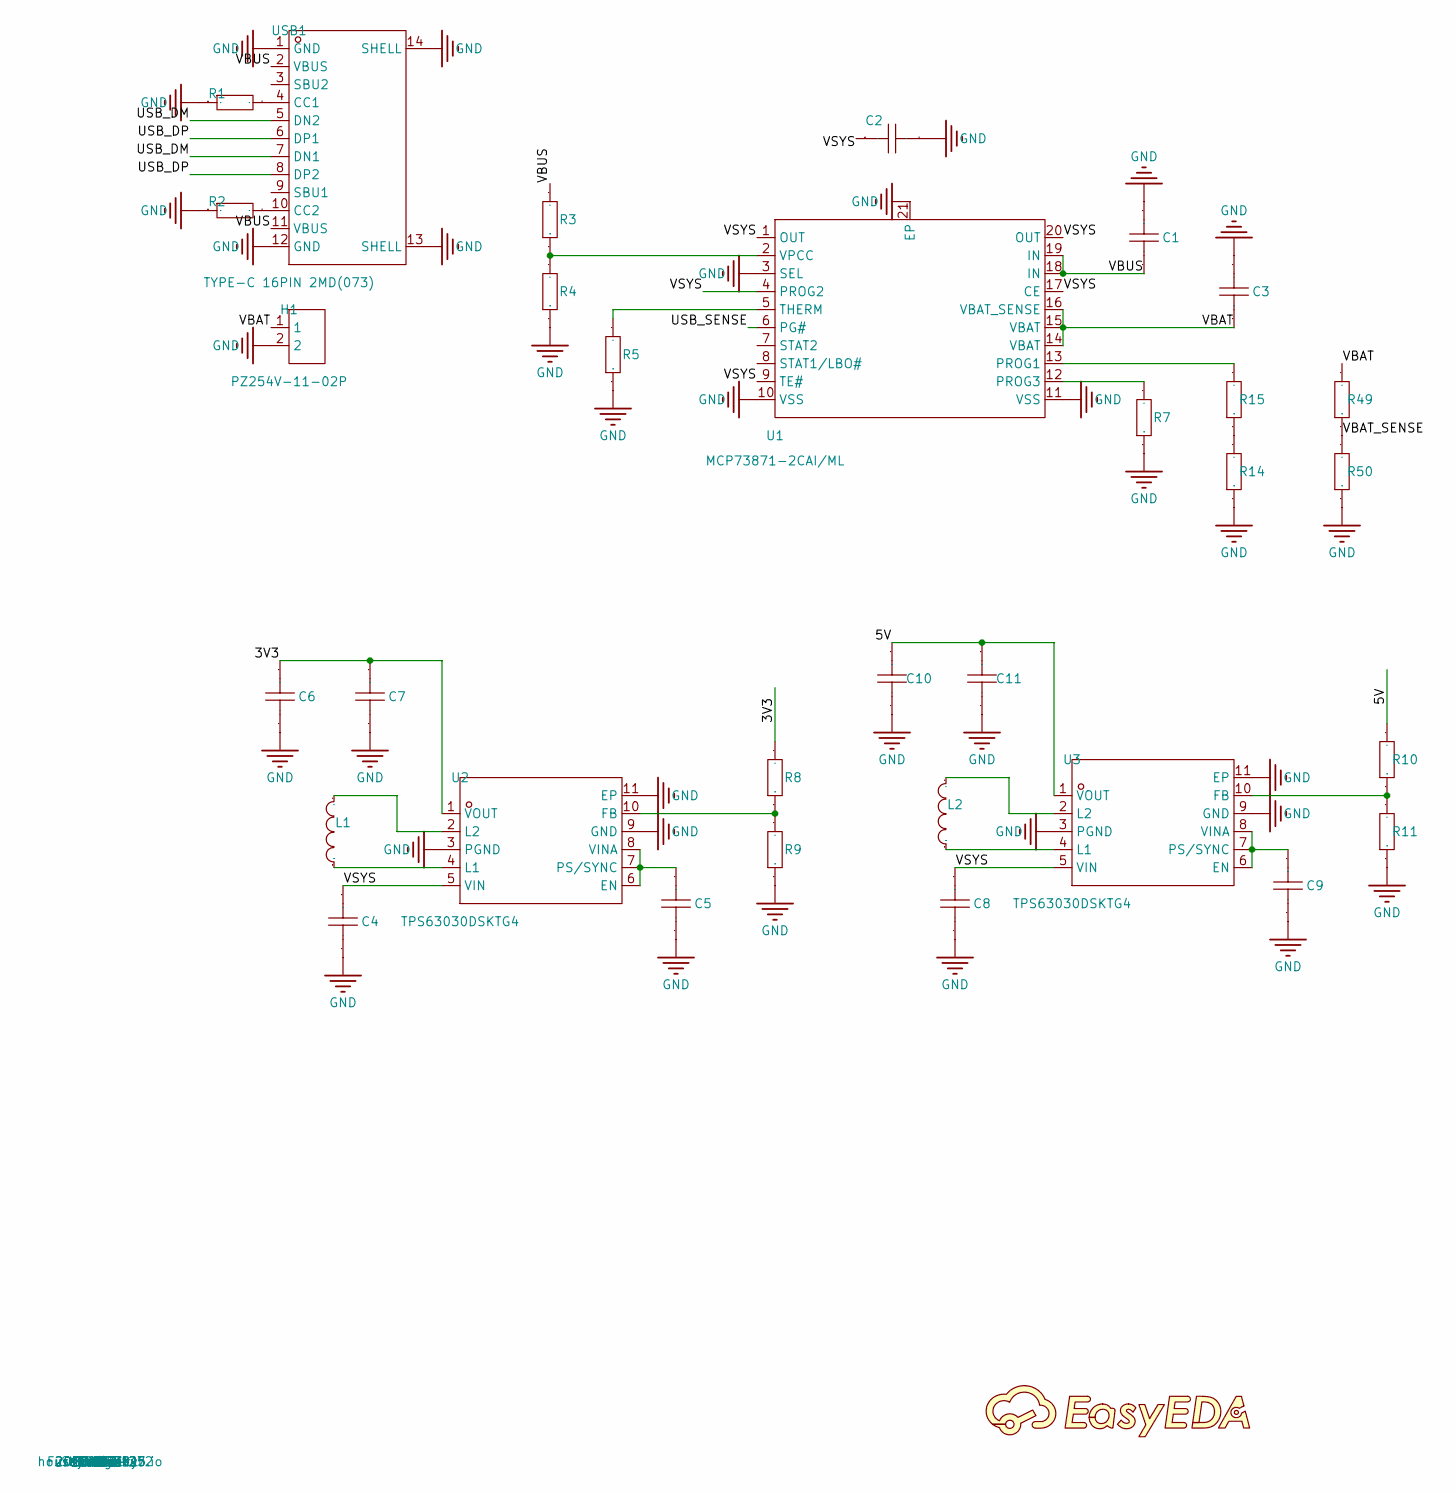
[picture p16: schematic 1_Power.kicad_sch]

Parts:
C1, C4, C6, C7, C8, C10, C11: 10uF; C0603; Manufacturer Part C0603B106M007T; LCSC Part Name 10uF ±20% 6.3V
C2, C3: 4.7uF; C0603; Manufacturer Part CL10A475KP8NNNC; LCSC Part Name 4.7uF ±10% 10V
C5, C9: 100nF; C0603; Manufacturer Part CC0603KRX7R9BB104; LCSC Part Name 100nF ±10% 50V
H1: PZ254V-11-02P; HDR-TH_2P-P2.54-V-M; Manufacturer Part PZ254V-11-02P; LCSC Part Name 1x2P 间距:2.54mm 方针 直插
L1, L2: 1.5uH; L0603; Manufacturer Part LB3218T1R5M; LCSC Part Name 1.5uH ±20%
R1, R2: 5.1kΩ; R0603; Manufacturer Part HoAR0603-1/10W-5.1KR-0.1%-TCR25; LCSC Part Name 陶瓷电阻 5.1kΩ ±0.1% 100mW
R3: 330kΩ; R0603; Manufacturer Part HPCR0603F330KK9; LCSC Part Name 厚膜电阻 330kΩ ±1%
R4: 110kΩ; R0603; Manufacturer Part PTFR0603B110KN9; LCSC Part Name 薄膜电阻 110kΩ ±0.1% 100mW
R5: 10kΩ; R0603; Manufacturer Part SCR0603J10K; LCSC Part Name 厚膜电阻 10kΩ ±5% 100mW
R7: 100kΩ; R0603; Manufacturer Part SCR0603F100K; LCSC Part Name 厚膜电阻 100kΩ ±1% 100mW
R8: 1.13MΩ; R0603; Manufacturer Part RTT031134FTP; LCSC Part Name 厚膜电阻 1.13MΩ ±1% 100mW
R9, R11: 200kΩ; R0603; Manufacturer Part SCR0603F200K; LCSC Part Name 厚膜电阻 200kΩ ±1% 100mW
R10: 1.8MΩ; R0603; Manufacturer Part FRC0603J185TS; LCSC Part Name 1.8MΩ ±5% 100mW 厚膜电阻
R14, R15, R49, R50: 1kΩ; R0603; Manufacturer Part 0603WAF1001T5E; LCSC Part Name 1kΩ ±1% 100mW 厚膜电阻
U1: MCP73871-2CAI/ML; QFN-20_L4.0-W4.0-P0.50-BL-EP2.7; Manufacturer Part MCP73871-2CAI/ML; LCSC Part Name 独立系统负载共享及锂离子/锂聚合物电池充电管理控制器
U2, U3: TPS63030DSKTG4; SON-10_L2.5-W2.5-P0.50-TL-EP; Manufacturer Part TPS63030DSKTG4; LCSC Part Name TPS63030DSKTG4
USB1: TYPE-C 16PIN 2MD(073); USB-C-SMD_TYPE-C-6PIN-2MD-073; Manufacturer Part TYPE-C 16PIN 2MD(073); LCSC Part Name Type-C 母 卧贴

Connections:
3V3: C6.1, C7.1, R8.2, U2.1 (VOUT); also elsewhere on the board
5V: C10.1, C11.1, R10.2, U3.1 (VOUT); also elsewhere on the board
$1N480: R1.2, USB1.4 (CC1)
$1N506: R2.2, USB1.10 (CC2)
$1N1632: R3.1, R4.2, U1.2 (VPCC)
$1N1764: R5.2, U1.5 (THERM)
$1N1839: R15.2, U1.13 (PROG1)
$1N1881: R7.2, U1.12 (PROG3)
$1N2370: C5.1, U2.6 (EN), U2.7 (PS/SYNC), U2.8 (VINA)
$1N2432: L1.2, U2.2 (L2)
$1N2438: L1.1, U2.4 (L1)
$1N2461: R8.1, R9.2, U2.10 (FB)
$1N3033: R10.1, R11.2, U3.10 (FB)
$1N3038: L2.2, U3.2 (L2)
$1N3051: C9.1, U3.6 (EN), U3.7 (PS/SYNC), U3.8 (VINA)
$1N3063: L2.1, U3.4 (L1)
$1N4175: R14.2, R15.1
USB_DM: USB1.5 (DN2), USB1.7 (DN1); also elsewhere on the board
USB_DP: USB1.6 (DP1), USB1.8 (DP2); also elsewhere on the board
USB_SENSE: U1.6 (PG#); also elsewhere on the board
VBAT: C3.1, H1.1, R49.2, U1.14 (VBAT), U1.15 (VBAT), U1.16 (VBAT_SENSE)
VBAT_SENSE: R49.1, R50.2; also elsewhere on the board
VBUS: C1.2, R3.2, U1.18 (IN), U1.19 (IN), USB1.2 (VBUS), USB1.11 (VBUS)
VSYS: C2.1, C4.1, C8.1, U1.1 (OUT), U1.4 (PROG2), U1.9 (TE#), U1.17 (CE), U1.20 (OUT), U2.5 (VIN), U3.5 (VIN)

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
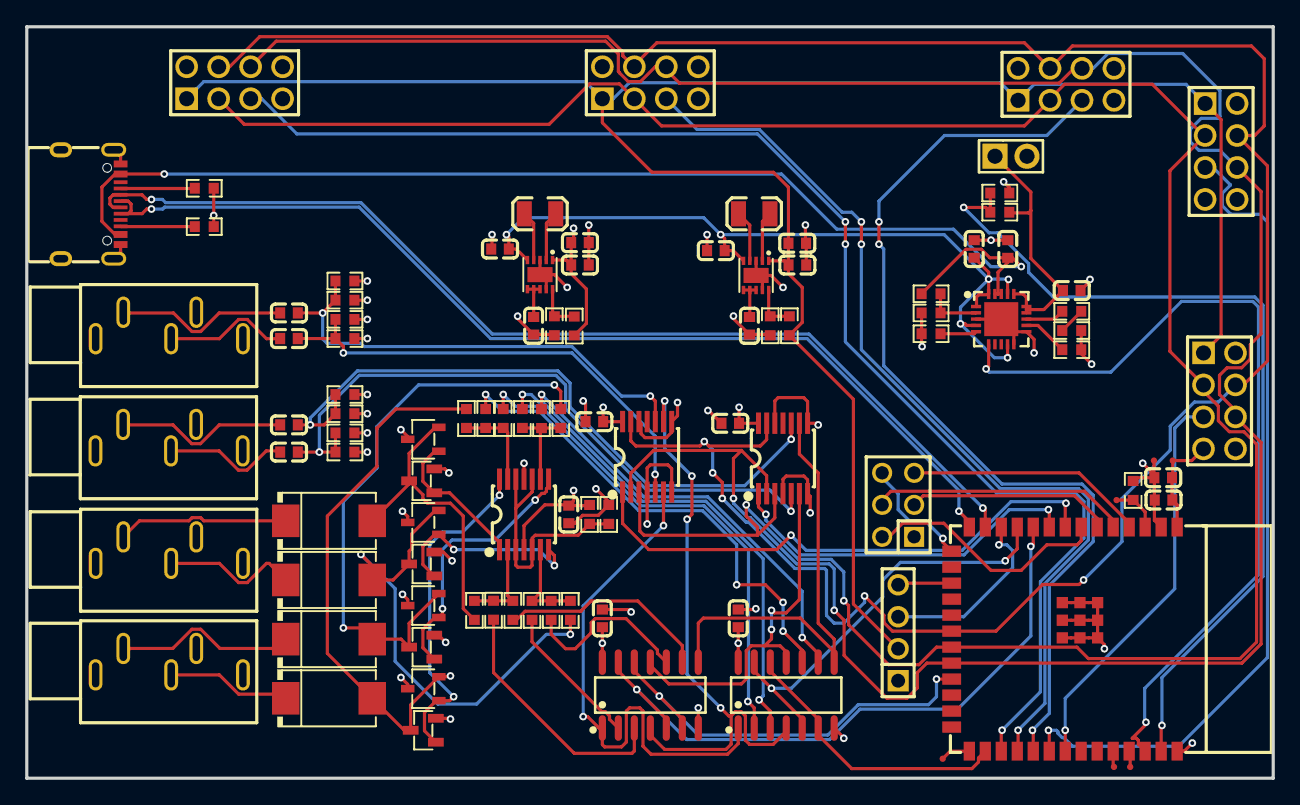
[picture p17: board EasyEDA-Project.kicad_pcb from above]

Board: 4 copper layers, 99.0 x 59.7 mm, 101 parts (0 on the bottom side), 87 nets.

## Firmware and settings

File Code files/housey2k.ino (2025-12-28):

#include <Wire.h>
#include <SPI.h>
#include <String.h>
#include <LiquidCrystal_I2C.h>
#include <MCP4261.h>

// SPI Bus BEGIN
#define MOD_CS1 36
#define MOD_CS2 37
#define MOD_CS3 38
#define MOD_CS4 39
#define MOD_CS5 40

#define P1_CS 15
#define P2_CS 16
// SPI Bus END

// GPIO BEGIN
#define ENTER 3
#define UP 4
#define DOWN 5
#define RIGHT 6
#define LEFT 7

#define CTRL_IN1_OUT1 17
#define CTRL_IN1_OUT2 18
#define CTRL_IN2_OUT1 21
#define CTRL_IN2_OUT2 35
// GPIO END

// BUS BEGIN
#define LCD_ADDR 0x27
#define SDA 8
#define SCL 9

#define MISO 12
#define MOSI 13
#define SCK 14
// BUS END

LiquidCrystal_I2C lcd(LCD_ADDR, 20, 4);
MCP4261 pot1(P1_CS, 255, &SPI);
MCP4261 pot2(P2_CS, 255, &SPI);

// scan for I2C devices
void I2C_Scan(void)
{
  byte error, address;
  int nDevices;

  Serial.println("Scanning...");
  nDevices = 0;
  for(address = 1; address < 127; address++ ) {
    Wire.beginTransmission(address);
    error = Wire.endTransmission();
    if (error == 0) {
      Serial.print("I2C device found at address 0x");
      if (address<16) {
        Serial.print("0");
      }
      Serial.println(address, HEX);
      nDevices++;
    }
    else if (error==4) {
      Serial.print("Unknow error at address 0x");
      if (address<16) {
        Serial.print("0");
      }
      Serial.println(address, HEX);
    }    
  }
  if (nDevices == 0) {
    Serial.println("No I2C devices found\n");
  }
  else {
    Serial.println("done\n");
  }
}

// writes SPI
void spiSendBuffer(const uint8_t *buf, size_t len) {
  for (size_t i = 0; i < len; i++) {
    SPI.transfer(buf[i]);
  }
}

// reads SPI
void spiReadBuffer(uint8_t *buf, size_t len) {
  for (size_t i = 0; i < len; i++) {
    buf[i] = SPI.transfer(0x00);
  }
}

// detect ports with modules connected
String Module_scan() {
  static const uint8_t detectCmd[] = { 'D','E','T','E','C','T' };
  uint8_t reply[4];

  const uint8_t csList[] = {
    MOD_CS1,
    MOD_CS2,
    MOD_CS3,
    MOD_CS4,
    MOD_CS5
  };

  String output;
  output.reserve(sizeof(csList));

  SPI.beginTransaction(SPISettings(
    500000,
    MSBFIRST,
    SPI_MODE0
  ));

  for (size_t i = 0; i < sizeof(csList); i++) {
    digitalWrite(csList[i], LOW);
    delayMicroseconds(5);

    spiSendBuffer(detectCmd, sizeof(detectCmd));
    delayMicroseconds(20);          // give slave time
    spiReadBuffer(reply, sizeof(reply));

    digitalWrite(csList[i], HIGH);

    output += (memcmp(reply, "HERE", 4) == 0) ? '1' : '0';
    delay(5);
  }

  SPI.endTransaction();
  return output;
}

// writes a debug message to UART and to the LCD during boot
void print(String msg, bool printToLCD_Y3) {
  Serial.println(msg);
  if (!printToLCD_Y3) { return; }
  lcd.setCursor(0, 3);
  lcd.print("                    ");
  lcd.setCursor(0, 3);
  lcd.print(msg);
}

// write/read test for the MCP4261, used to confirm the board is fine
bool RW_MCP4261(MCP4261 pot, int wiper) {
  bool success = false;
  pot.setValue(wiper, 123);
  if (pot.getValueDevice(wiper) == 123) {
    success = true;
  }
  return success;
}

void halt() {
  while (true) {}
}

String Connected_modules;

bool RenderedMenu;
bool RenderedArrow;

int ArrowX;
int ArrowY;
int PrevArrowX;
int PrevArrowY;

String CurrMenu;

bool UpPressed;
bool DownPressed;
bool RightPressed;
bool LeftPressed;

int ArrowRawX;
int ArrowRawY;

void setup(void) {
  Serial.begin(115200);
  print("HouseY2K OS", false);

  Wire.begin(SDA, SCL);
  print("Initialized I2C bus", false);

  I2C_Scan();
  print("Hardcoded LCD addr: #define LCD_ADDR ", false);
  Serial.println(LCD_ADDR);

  lcd.init();
  print("LCD init() done", true);
  lcd.backlight();
  print("LCD backlight() done", true);

  lcd.print("FurModularity DEV FW");
  lcd.setCursor(0, 1);
  lcd.print("HouseY2K OS V0.1");
  lcd.setCursor(0, 2);
  lcd.print("Booting...");
  print("Initializing SPI...", true);
  SPI.begin(SCK, MISO, MOSI, -1);
  delay(100);

  print("Initializing pins...", true);
  pinMode(MOD_CS1, OUTPUT);
  pinMode(MOD_CS2, OUTPUT);
  pinMode(MOD_CS3, OUTPUT);
  pinMode(MOD_CS4, OUTPUT);
  pinMode(MOD_CS5, OUTPUT);

  pinMode(ENTER, INPUT_PULLUP);
  pinMode(UP, INPUT_PULLUP);
  pinMode(DOWN, INPUT_PULLUP);
  pinMode(RIGHT, INPUT_PULLUP);
  pinMode(LEFT, INPUT_PULLUP);

  pinMode(CTRL_IN1_OUT1, INPUT_PULLUP);
  pinMode(CTRL_IN1_OUT2, INPUT_PULLUP);
  pinMode(CTRL_IN2_OUT1, INPUT_PULLUP);
  pinMode(CTRL_IN2_OUT2, INPUT_PULLUP);

  delay(100);

  print("POST MCP4261", true);
  delay(100);

  print("INIT MCP4261", true);
  pot1.begin();
  pot2.begin();
  delay(100);

  print("RW MCP4261 IC1 W0", true);
  if (RW_MCP4261(pot1, 0)) {
    print("OK", true);
  } else {
    print("ERROR IC1 W0", true);
    halt();
  }

  delay(100);

  print("RW MCP4261 IC1 W1", true);
  if (RW_MCP4261(pot1, 1)) {
    print("OK", true);
  } else {
    print("ERROR IC1 W1", true);
    halt();
  }

  delay(100);

  print("RW MCP4261 IC2 W0", true);
  if (RW_MCP4261(pot2, 0)) {
    print("OK", true);
  } else {
    print("ERROR IC2 W0", true);
    halt();
  }

  delay(100);

  print("RW MCP4261 IC2 W1", true);
  if (RW_MCP4261(pot2, 1)) {
    print("OK", true);
  } else {
    print("ERROR IC2 W1", true);
    halt();
  }

  delay(100);
  

  print("Scanning modules...", true);
  Connected_modules = Module_scan();

  print("mdet:" + Connected_modules, true);

  delay(1000);
  print("Initializing vars", true);

  RenderedMenu = false;
  CurrMenu = "NULL";

  RenderedArrow = false;
  ArrowX = 0;
  ArrowY = 0;

  PrevArrowX = 0;
  PrevArrowY = 0;

  ArrowRawX = 0;
  ArrowRawY = 0;

  UpPressed = false;
  DownPressed = false;
  RightPressed = false;
  UpPressed = false;
  delay(100);
  print("BootOK LoadOS", true);
}

// renders the initial menu
void RenderMainMenu(String Mods) {
  lcd.clear();
  lcd.setCursor(0, 0);

  lcd.print(" MODS USB ");
  lcd.setCursor(0, 1);
  lcd.print("MIXER PWR");
  lcd.setCursor(0, 2);
  lcd.print(" WiFi BATT");
  lcd.setCursor(0, 2);
  lcd.print(" BLE ");
}


// draws the arrow to a position on the screen and cleans the old one
void RenderArrow(int X, int Y) {
  RenderedArrow = true;
  lcd.setCursor(PrevArrowX, PrevArrowY);
  lcd.print(" ");
  lcd.setCursor(X, Y);
  lcd.print(">");
  PrevArrowX = X;
  PrevArrowY = Y;
}

// Gets the position to write the arrow on screen, rawpos is the numerical value based on the increments or decrements from left/right buttons
int GetArrowXPos(int rawPos) {
  if (CurrMenu == "MAIN") {
    if (rawPos == 0) {
      return 0;
    } else if (rawPos == 1) {
      return 5;
    } else if (rawPos == 2) {
      return 9;
    }
  }
  return 0;
}

// Gets the position to write the arrow on screen, rawpos is the numerical value based on the increments or decrements from up/down buttons
int GetArrowYPos(int rawPos) {
  /*if (CurrMenu == "MAIN") {
    if (rawPos == 0) {
      return 0;
    } else if (rawPos == 1) {
      return 1;
    } else if (rawPos == 2) {
      return 2;
    }
  }*/
  return rawPos;
}

void loop(void) {

  if (!digitalRead(UP) && !UpPressed) {
    UpPressed = true;
    RenderedArrow = false;
    ArrowRawY++;
  } else if (digitalRead(UP)) {
    UpPressed = false;
  }

  if (!digitalRead(DOWN) && !DownPressed) {
    DownPressed = true;
    RenderedArrow = false;
    ArrowRawY--;
  } else if (digitalRead(DOWN)) {
    DownPressed = false;
  }

  if (!digitalRead(RIGHT) && !RightPressed) {
    RightPressed = true;
    RenderedArrow = false;
    ArrowRawX++;
  } else if (digitalRead(RIGHT)) {
    RightPressed = false;
  }

  if (!digitalRead(LEFT) && !LeftPressed) {
    LeftPressed = true;
    RenderedArrow = false;
    ArrowRawX--;
  } else if (digitalRead(LEFT)) {
    LeftPressed = false;
  }

  if (CurrMenu == "NULL")
  {
    CurrMenu = "MAIN";
    RenderedMenu = true;
    RenderMainMenu(Connected_modules);
  }

  if (!RenderedArrow) {
    RenderArrow(GetArrowXPos(ArrowRawX), GetArrowYPos(ArrowRawY));
  }
}

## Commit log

2025-12-27 Rename Captura de tela 2025-12-27 185347.png to PCB_Final
2026-01-08 Revise README with new images and circuit schematics
    Updated images and added schematics for power, digital, and audio circuits.
2026-01-08 Update BOM, sch and readme for review
    [BOM.csv, BOM_Board1_Schematic1_2025-12-28.xlsx]
2026-01-08 Added missing PCB image
2026-01-23 Add KiCad mirror
    [1_Power.kicad_sch, 2_MCU.kicad_sch, 3_Audio.kicad_sch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]
2026-01-24 Add 3D files
    [FurModularity case.f3d, FurModularity case.step]
2026-01-31 Commit I forgot
    [1_Power.kicad_sch, 2_MCU.kicad_sch, 3_Audio.kicad_sch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]
2026-01-31 add more case img
    aaaaaaaaahhhhhhhhhhhhhhh
2026-02-14 Rounded corners on 3D
    Rounded corners on 3D
    [FurModularity case.f3d, FurModularity case.step]
